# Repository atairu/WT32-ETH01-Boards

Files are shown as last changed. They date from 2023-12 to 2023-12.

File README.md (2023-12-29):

KiCAD files for WT32-ETH01 MCU breakout board PCBs. PCBs includes

* 1-Port with USB 2.0 receptacle
* 1-Port with USB type C receptacle
* 2-Port with USB 2.0 receptacle
* 4-Port with USB 2.0 receptacle
* 8-Port with USB 2.0 receptacle

The boards feature multi voltage on the input between 5v - 24v and can be used to program WT32-ETH01 using on-board serial to UART protocol IC with WLED.

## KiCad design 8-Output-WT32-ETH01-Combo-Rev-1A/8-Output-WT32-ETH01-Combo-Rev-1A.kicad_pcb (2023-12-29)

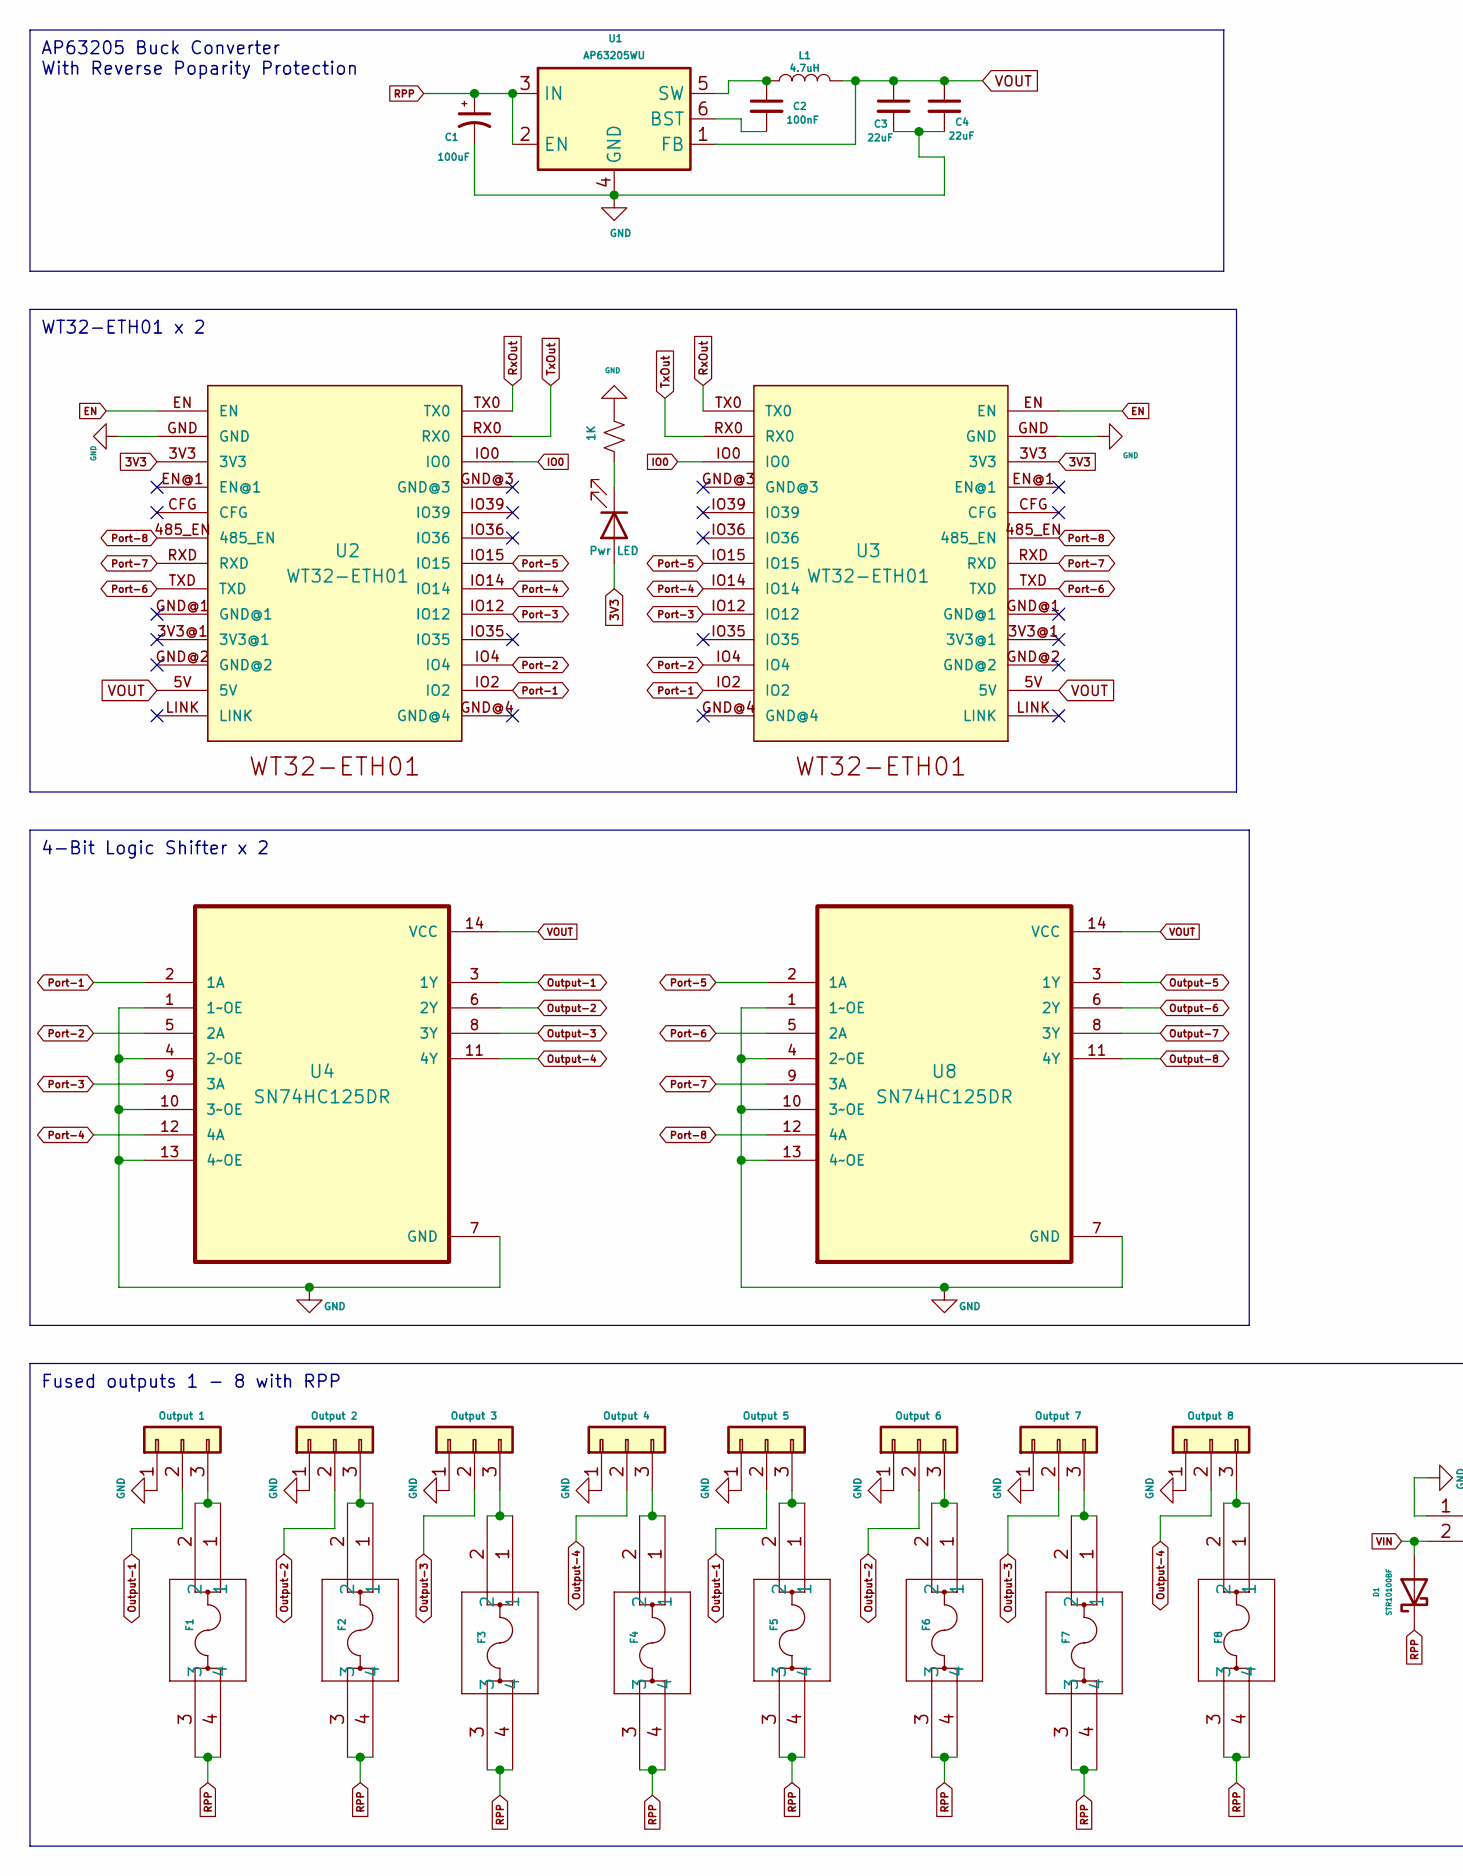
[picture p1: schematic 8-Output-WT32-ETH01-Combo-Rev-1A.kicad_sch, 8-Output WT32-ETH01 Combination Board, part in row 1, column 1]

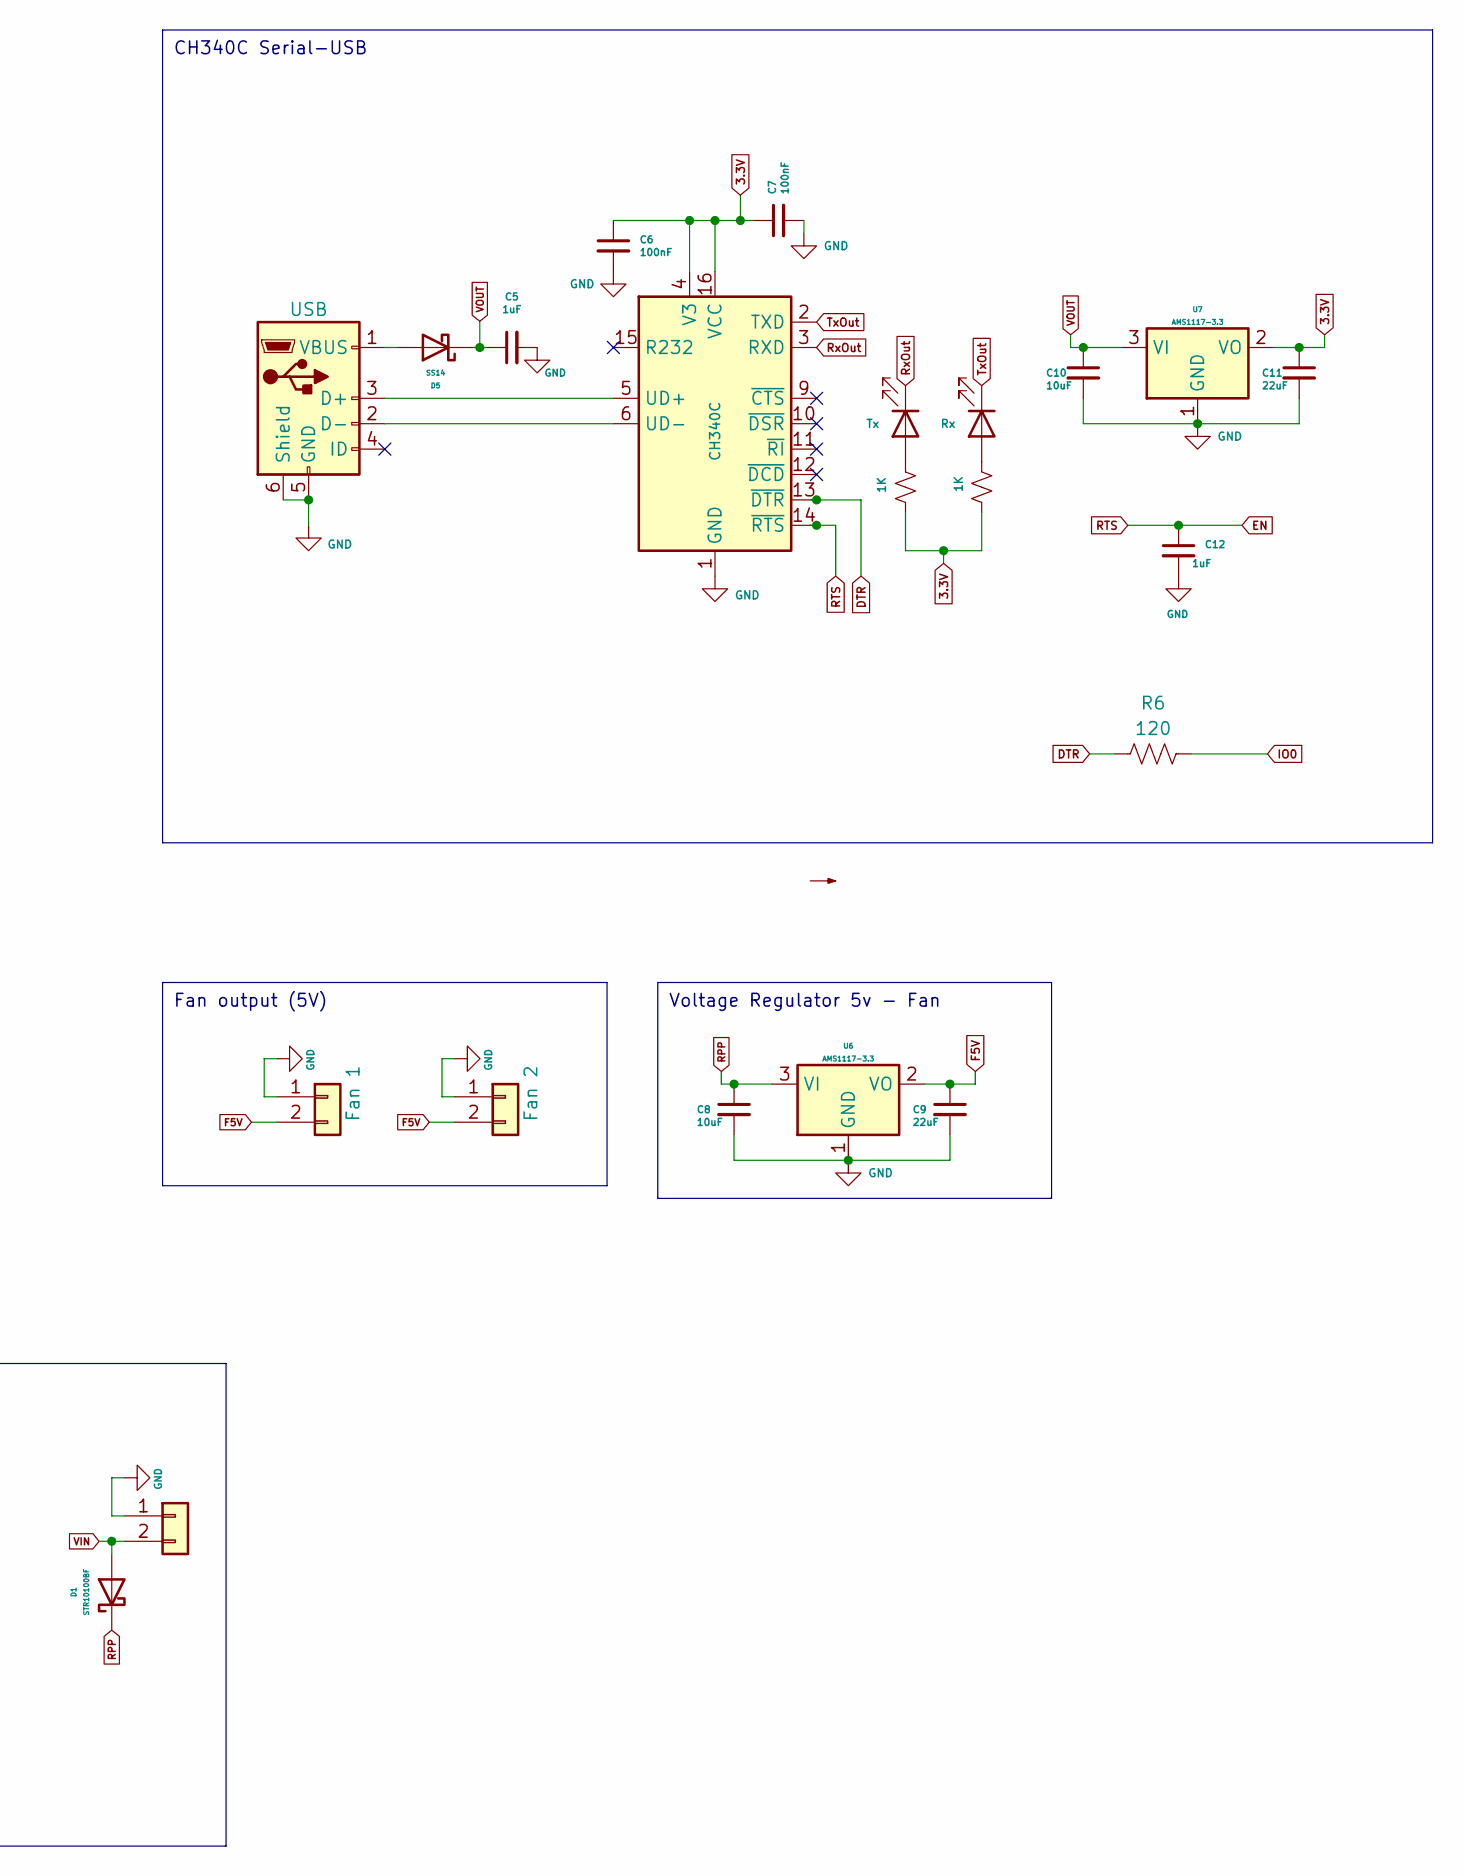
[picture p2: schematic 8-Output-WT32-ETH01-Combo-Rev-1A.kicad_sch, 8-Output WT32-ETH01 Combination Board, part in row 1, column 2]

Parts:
C1: 100uF; CP_Elec_6.3x5.4
C2, C6, C7: 100nF; C_0805_2012Metric_Pad1.18x1.45mm_HandSolder
C3, C4, C9, C11: 22uF; C_0805_2012Metric_Pad1.18x1.45mm_HandSolder
C5, C12: 1uF; C_0805_2012Metric_Pad1.18x1.45mm_HandSolder
C8, C10: 10uF; C_0805_2012Metric_Pad1.18x1.45mm_HandSolder
D1: STR10100BF; D_SMB_Handsoldering
D2: Pwr LED; LED_0805_2012Metric_Pad1.15x1.40mm_HandSolder
D3: Tx; LED_0805_2012Metric_Pad1.15x1.40mm_HandSolder
D4: Rx; LED_0805_2012Metric_Pad1.15x1.40mm_HandSolder
D5: SS14; D_SOD-323_HandSoldering
F1, F2, F3, F4, F5, F6, F7, F8: MCCQ-122_MTC
J1: 4.5-28V Power Input; 1714955
J2: USB; USB_Micro-B_Unknown_5s_SMT
J3: Fan 1; JST_XH_B2B-XH-A_1x02_P2.50mm_Vertical
J4: Fan 2; JST_XH_B2B-XH-A_1x02_P2.50mm_Vertical
JST1: Output 1; TerminalBlock_Phoenix_MKDS-1,5-3-5.08_1x03_P5.08mm_Horizont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
JST2: Output 2; TerminalBlock_Phoenix_MKDS-1,5-3-5.08_1x03_P5.08mm_Horizont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
JST3: Output 3; TerminalBlock_Phoenix_MKDS-1,5-3-5.08_1x03_P5.08mm_Horizont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
JST4: Output 4; TerminalBlock_Phoenix_MKDS-1,5-3-5.08_1x03_P5.08mm_Horizont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
JST5: Output 5; TerminalBlock_Phoenix_MKDS-1,5-3-5.08_1x03_P5.08mm_Horizont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
JST6: Output 6; TerminalBlock_Phoenix_MKDS-1,5-3-5.08_1x03_P5.08mm_Horizont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
JST7: Output 7; TerminalBlock_Phoenix_MKDS-1,5-3-5.08_1x03_P5.08mm_Horizont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
JST8: Output 8; TerminalBlock_Phoenix_MKDS-1,5-3-5.08_1x03_P5.08mm_Horizont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
L1: 4.7uH; L_Taiyo-Yuden_MD-5050
R1, R2, R3: 1K; R_0805_2012Metric_Pad1.20x1.40mm_HandSolder
R6: 120; R_0805_2012Metric_Pad1.20x1.40mm_HandSolder
U1: AP63205WU; TSOT-23-6
U2, U3: WT32-ETH01; WT32_ETH01
U4, U8: SN74HC125DR; SOIC127P600X175-14N
U5: CH340C; SOP-16_3.9x9.9mm_P1.27mm
U6, U7: AMS1117-3.3; SOT-223-3_TabPin2

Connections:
3.3V: C6.1, C7.1, C11.1, R2.1, R3.2, U5.4 (V3), U5.16 (VCC), U7.2 (VO)
3V3: D2.2 (A), U2.3V3, U3.3V3
DTR: R6.1, U5.13 (~DTR)
EN: C12.1, U2.EN, U3.EN, U5.14 (~RTS)
F5V: C9.1, J3.2, J4.2, U6.2 (VO)
GND: C1.2, C3.2, C4.2, C5.2, C6.2, C7.2, C8.2, C9.2, C10.2, C11.2, C12.2, J1.1, J2.5 (GND), J2.6 (Shield), J3.1, J4.1, JST1.1, JST2.1, JST3.1, JST4.1, JST5.1, JST6.1, JST7.1, JST8.1, R1.1, U1.4 (GND), U2.GND, U3.GND, U4.1 (1~OE), U4.4 (2~OE), U4.7 (GND), U4.10 (3~OE), U4.13 (4~OE), U5.1 (GND), U6.1 (GND), U7.1 (GND), U8.1 (1~OE), U8.4 (2~OE), U8.7 (GND), U8.10 (3~OE), U8.13 (4~OE)
IO0: R6.2, U2.IO0, U3.IO0
unnamed: D2.1 (K), R1.2
unnamed: D3.2 (A), R2.2
unnamed: D4.2 (A), R3.1
unnamed: D5.2 (A), J2.1 (VBUS)
unnamed: J2.3 (D+), U5.5 (UD+)
unnamed: J2.2 (D-), U5.6 (UD-)
unnamed: F1.1, F1.2, JST1.3
unnamed: F2.1, F2.2, JST2.3
unnamed: F3.1, F3.2, JST3.3
unnamed: F4.1, F4.2, JST4.3
unnamed: F5.1, F5.2, JST5.3
unnamed: F6.1, F6.2, JST6.3
unnamed: F7.1, F7.2, JST7.3
unnamed: F8.1, F8.2, JST8.3
unnamed: C2.2, U1.6 (BST)
unnamed: C2.1, L1.1, U1.5 (SW)
Output-1: JST1.2, JST5.2, U4.3 (1Y)
Output-2: JST2.2, JST6.2, U4.6 (2Y)
Output-3: JST3.2, JST7.2, U4.8 (3Y)
Output-4: JST4.2, JST8.2, U4.11 (4Y)
Output-5: U8.3 (1Y)
Output-6: U8.6 (2Y)
Output-7: U8.8 (3Y)
Output-8: U8.11 (4Y)
Port-1: U2.IO2, U3.IO2, U4.2 (1A)
Port-2: U2.IO4, U3.IO4, U4.5 (2A)
Port-3: U2.IO12, U3.IO12, U4.9 (3A)
Port-4: U2.IO14, U3.IO14, U4.12 (4A)
Port-5: U2.IO15, U3.IO15, U8.2 (1A)
Port-6: U2.TXD, U3.TXD, U8.5 (2A)
Port-7: U2.RXD, U3.RXD, U8.9 (3A)
Port-8: U2.485_EN, U3.485_EN, U8.12 (4A)
RPP: C1.1, C8.1, D1.1 (K), F1.3, F1.4, F2.3, F2.4, F3.3, F3.4, F4.3, F4.4, F5.3, F5.4, F6.3, F6.4, F7.3, F7.4, F8.3, F8.4, U1.2 (EN), U1.3 (IN), U6.3 (VI)
RxOut: D3.1 (K), U2.TX0, U3.TX0, U5.3 (RXD)
TxOut: D4.1 (K), U2.RX0, U3.RX0, U5.2 (TXD)
VIN: D1.2 (A), J1.2
VOUT: C3.1, C4.1, C5.1, C10.1, D5.1 (K), L1.2, U1.1 (FB), U2.5V, U3.5V, U4.14 (VCC), U7.3 (VI), U8.14 (VCC)

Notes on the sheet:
AP63205 Buck Converter With Reverse Poparity Protection
4-Bit Logic Shifter x 2
Voltage Regulator 5v - Fan
CH340C Serial-USB
WT32-ETH01 x 2
Fused outputs 1 - 8 with RPP
Fan output (5V)

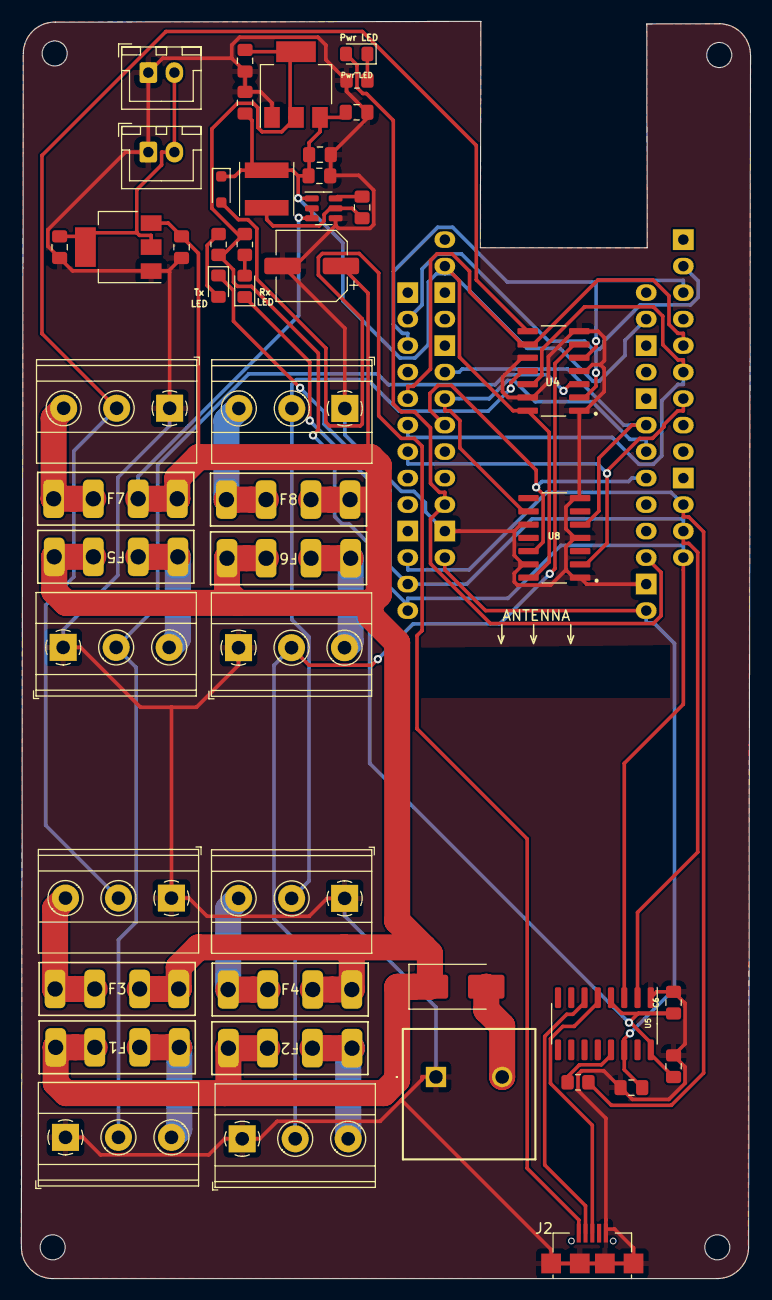
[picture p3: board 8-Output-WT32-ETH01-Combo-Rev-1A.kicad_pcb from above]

Board: 2 copper layers, 69.9 x 120.5 mm, 50 parts (1 on the bottom side), 40 nets.
